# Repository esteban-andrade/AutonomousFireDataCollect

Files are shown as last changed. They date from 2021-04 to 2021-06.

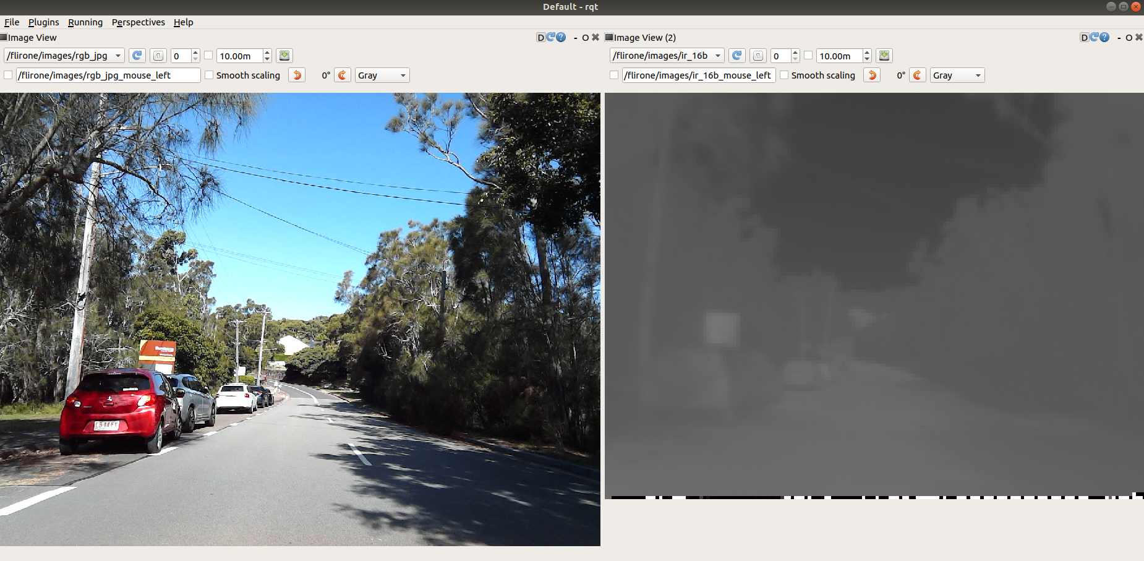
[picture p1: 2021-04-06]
flir_one_node/demo/Screenshot from 2021-02-14 20-05-20.png

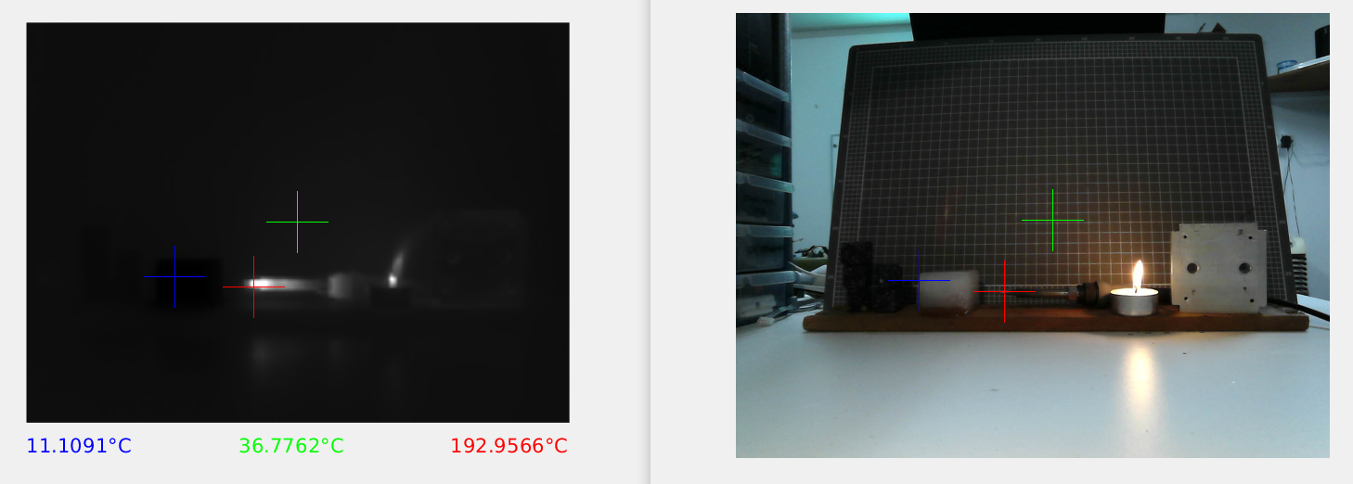
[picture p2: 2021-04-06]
flir_one_node/demo/Screenshot from 2021-02-16 15-40-37.png

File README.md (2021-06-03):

# AutonomousFireDataCollect

This repository deals with the Data Monitoring & Collection for Early-Stage Bushfires project for MMD AUT2021 held at UTS.

In recent years, there has been an international increase in the number, severity, and impact of bushfires on rural communities, biodiversity and subsequently both national and international economies. Currently, emergency services have no method to detect or collect data to monitor the early stages of remote bushfires. 

Currently, emergency services have limited methods to collect data to detect or monitor remote bushfires in their early stages. The first step is to build up a dataset of bushfire information from a range of sensors. A basic user-responsive prototype has been produced to collect and monitor bushfire data in low intensity areas which has been showcased here.



The following folders contain a solution that aids to capture data in order to train som ML models.

The main objective is to capture data using a thermal camera(Flir) along with auxiliary sensors(Temperature,Humidity,Pressure,etc.).
This will be processed using a corresponding ROS NODE ` flir_one_node` and with the Launch files start the data acquisition process smoothly and store it in a ROSBAG with the timestamp.

All Main components of this project are detailed in the folder below

* The Data Processing folder contains the script required to plot data in MATLAB from a video source and data set.
* The Electronics folder contains the code and PCB schematic/design files created for the prototype device.
* The Interaction folder contains the scripts required to accept commands from the Teensy device to the computer to trigger start and stop recording.
* The flir_one_node folder contains the files required to setup the FLIR ONE camera.

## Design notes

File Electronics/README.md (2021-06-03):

# Electronics

#### The code folder contains the firmware required for the following microcontrollers:
1. [`Sensors-Teensy4.0`](https://github.com/esteban-andrade/AutonomousFireDataCollect/tree/main/Electronics/code/Sensors-Teensy4.0): Once loaded onto the Teensy 4.0, it's main purpose is to collect data from all attached sensors and parse the data over Serial to ROS SERIAL. The device will all the user to start and stop data recording using a user interface panel on board.
2. [`ESP8266`](https://github.com/kyleprr/AutonomousFireDataCollect/tree/main/Electronics/Atmega328p-GPS): The ESP8266 module is intended to collect GPS NEMA data and translate that into GPS coordinates for use. The ESP8266 will parse the data and send it over UART to the Teensy 4.0. 

Note: The firmware is written in VSCode using PlatformIOIDE. Please install the required software to modify the code.

The pcb_project_files folder contains the Altium Designer schematic and PCB files for the four PCB modules as shown below:

### Custom Printed Circuit Boards Developed

#### 1. Main Controller:


#### 2. Power Management:


#### 3. Sensors:


#### 4. User Controller:


#### 5. Connections/Layout:


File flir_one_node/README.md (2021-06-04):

# FLIR One Interfacing Node

This package is used to open a connection to the FLIR one camera and publish data from it to various ROS topics.

This guide assumes that [ROS](https://www.ros.org/) has been installed and setup on the user's system

Package has been tested using `ROS Melodic` running on `Ubuntu 18.04`

## 1. Allow access to USB device

The FLIR One has a vendor ID of `0x09CB` and a porduct ID of `0x1996`

To allow the package to access data from this, create a new `rules` file

```
sudo nano /etc/udev/rules.d/51-usb-flir-one.rules
```

Add the following text to this file

```
SUBSYSTEMS=="usb", ATTRS{idVendor}=="09cb", ATTRS{idProduct}=="1996", MODE:="0666"
```

Restart the system

## 2. Create and run the ROS package

Ensure that this git repository is contained within the `src` folder of the `catkin_ws` directory.

Run `catkin_make` from within the `catkin_ws` directory. Otherwise perform a `catkin build`

Ensure the package can be run by executing the following command from the `catkin_ws` directory: 

```
source devel/setup.bash
```

If there is an issue once when running the program starts on the computer unit. Refresh the bashrc.
```
source devel/setup.bash
```

Ensure an instance of ROS is running on the machine

```
roscore
```

Ensuring the camera is connected and powered on, run the ROS package

```
rosrun flir_one_node flir_one_node
```
## Launch Files

Alternatively there are a series of launch files that can be used to start the rosnode. These will allow a simpler approach when executing the ROS nodes for different purposes such as Visualization or Data Recording

### For Visualization 

Type the following command in a terminal. It will start the node and it will broadcast both RBG and Depth Images

```
roslaunch flir_one_node flir_data_vis.launch
```

### For Recording
 
 Type the following command in the terminal to record a ROSBAG of images and sensor data. The ROSBAG will use the timestamp of when the recording process started.
 
```
roslaunch flir_one_node flir_data_vis.launch
```

The data can be viewed using RQT (or similar) on the following topics:

```
/camera_flir_node/rgb/image_raw
/camera_flir_node/ir_8b/image_raw
/camera_flir_node/ir_16b/image_raw
/flirone/ok/status 
/sensors/data
```
The `/flirone/ok/status ` will broadcast the status of the connection of the Flir camera with the Intel Nuc. A boolean will be used and if the value is true there are no issues when using camera to record data.

If the Visualization Launch file is triggered it will use RQT as default for image visualization

## SensorData

The sensor data will be parsed using strings. 
Ensure that the microcontroller is defined as `/dev/ttyACM0`

The Node will send serial data to the microcontroller when it  is required to start and stop the sensor data acquisition process.

he topic `/sensors/data` will receive the sensor data from the teensy and it will parse the serial data as string and subsequenly advertised in this ROS topic.

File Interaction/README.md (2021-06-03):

# Interaction Section

This component describes the integration between the user interface and the system.

## Requirements.
Ensure to navigate to the `test folder` and compile the test  script
```
mkdir build 
cd build 
cmake ..
make
````

## Specifications.
This will generate an executable(program) that will be added to the `start-up` applications in ubuntu in order to start it automatically after boot.

It will read data from the serial port `/dev/ttyACM0` amd it will wait from input from the user in order to start recording data.

Once the user pressed the stop button it will terminate the data recording process.

## Integration
To integrate this open the `start-up` applications option in Ubuntu.
Add the path to the filed to the generated executable  `integration` to the new option and add a valid name.

Once the system reboots the application will start automatically.

## Extra components
Similarly under PythonSerial it is possible to user seral pythons scripts to acquire pure sensor data from the teensy and save them to CSV files.

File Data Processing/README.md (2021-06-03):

# MATLAB Data Plotting Video Generator

This document outlines how to use the MATLAB script `data_plotter.m` to visualise time-based graphical data with a live video.

## Dependencies

This script was prepared using MATLAB R2021a. No specialised toolboxes are required for use.

## Purpose and Overview

The purspose of this program is to take a descrete time-based dataset in a `.csv` format and visualise that data against a video in realtime.

## Usage Instructions

To use this script, a csv and supported video file is required, and should be placed within your MATLAB workspace.

These filenames should be placed in lines 6 and 9:

```
% Load data to plot
sensorData = readtable('<csv_file>');

% Load video to plot
v = VideoReader('<video_file>');
```

Lines 1-3 should be updated to show the rate at which data is captured in the csv file, the frame rate of the video and the frame number within the video where the data starts recording:

```
data_poll_rate_hz = 1;
frame_rate_fps = 30;
start_frame = 222;
```

Lines 11-55 setup the interface, and may be modified should elements of the GUI require changing, such as aspect ratio, video size or number of graphics.

Lines 58-62 create the video object to output. Here, the file format, frame rate and compression ratio (quality) can be set.

If the original video needs to be rotated, this can be done on line 69:

```
frame = imrotate(frame, 270);
```

Lines 80-113 plot the figures, and needs to be configured depending on what data you wish to show, and how you wish to show it.

For example, line 81 can be configured to extract the appropriate data from the csv table, as well as format the plot.

## Disclaimer

It is acknowledged that the modularity of this script is limited, and can be improved in several ways. The user should understand that this script was developed as a "hacky prototype" used to visualise data for a specific application. This software is provided "as is" and is used at your own risk.

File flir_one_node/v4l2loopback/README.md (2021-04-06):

# Using Video for Linux 2 (V4L2)

In the case where ROS is not available, the video data from the FLIR One can be streamed to Linux by running the appropriate drivers. This can be useful for testing and evaluation purposes.

## Testing Conditions

This procedure was tested on the following machines and operating systems:

1. DELL XPS 13 (with UEFI Secure Boot)
```
Kernel: 5.4.0-60-generic x86_64
bits: 64
Desktop: Gnome 3.28.4
Distro: Ubuntu 18.04.5 LTS
```

2. Lattepanda SBC
```
Ubuntu 16.04
```

## Device Setup

Install the following packages using the following

```
$ sudo apt-get install g++
$ sudo apt-get install libusb-1.0-0-dev
$ sudo apt-get install linux-generic
$ sudo apt-get install mplayer
```

Install `v4l2loopback` from [github](https://github.com/umlaeute/v4l2loopback). Follow the instructions in this repository to install.

To check that `v4l2loopback` has installed correctly, run the following:

```
$ sudo modprobe v4l2loopback
```

This will create a new virtual video device for the physical video devices connected to your system.

If an error message is received, refer to the troubleshooting steps in the `v4l2loopback` documentation. This will likely occur on UEFI secure boot devices, in which case, the module should be built [via DKMS](https://github.com/umlaeute/v4l2loopback#DKMS).

When working with DKMS, you need to be superuser through either of the following:

```
$ su
$ sudo -i
```

## Install

The first step is to create new dummy video devices for the FLIR One camera for the three image streams.

Assign a virtual video device to each existing video device and check what devices are connected to the system:

```
$ sudo modprobe v4l2loopback
$ v4l2-ctl --list-devices
```

You should see a list of devices and an associated video. You can also list the virtual video devices used as follows:

```
$ ls /dev/video*
```

Create the three new virtual video devices using the following command:

```
$ sudo modprobe v4l2loopback devices=3
```

Alternatively, you can specify the video number and name with the following

```
$ sudo modprobe v4l2loopback video_nr=<N>,<N+1>,<N+2> card_label="<Device name N>","<Device name N+1>","<Device name N+2>"
```

where N is the next available virtual video device.

For example, the following device has an internal webcam and two external USB cameras. Listing the devices gave the following result:

```
$ v4l2-ctl --list-devices
Integrated_Webcam_HD: Integrate (usb-0000:00:14.0-5):
	/dev/video0
	/dev/video1
	/dev/video2
	/dev/video3

USB2.0 UVC PC Camera: USB2.0 UV (usb-0000:3c:00.0-2.3.2.1.1.1):
	/dev/video4
	/dev/video5

Microsoft® LifeCam Studio(TM): (usb-0000:3f:00.0-1.2):
	/dev/video6
	/dev/video7
```

As there are eight devices already (0-7), three new additional devices will be created as video8, video9 and video10:

```
$ sudo modprobe v4l2loopback devices=3
$ v4l2-ctl --list-devices
Dummy video device (0x0000) (platform:v4l2loopback-000):
	/dev/video8

Dummy video device (0x0001) (platform:v4l2loopback-001):
	/dev/video9

Dummy video device (0x0002) (platform:v4l2loopback-002):
	/dev/video10

Integrated_Webcam_HD: Integrate (usb-0000:00:14.0-5):
	/dev/video0
	/dev/video1
	/dev/video2
	/dev/video3

USB2.0 UVC PC Camera: USB2.0 UV (usb-0000:3c:00.0-2.3.2.1.1.1):
	/dev/video4
	/dev/video5

Microsoft® LifeCam Studio(TM): (usb-0000:3f:00.0-1.2):
	/dev/video6
	/dev/video7
```

If not all dummy videos were created, you can try and reset v4l2loopback, which is loaded on boot (may occur especially if multiple video devices are connected). Recreate the devices again as follows:

```
$ sudo rmmod v4l2loopback
$ sudo modprobe v4l2loopback devices=3
$ v4l2-ctl --list-devices
```

The source code of [flirone.c](src/flirone.c) needs to then be modified to assign the video streams to one of these virtual devices (lines 41-51). Only the string for the video device name needs to be changed

```
#define VIDEO_DEVICE0 "/dev/video8"  // gray scale thermal image
#define FRAME_WIDTH0  160
#define FRAME_HEIGHT0 120

#define VIDEO_DEVICE1 "/dev/video9" // color visible image
#define FRAME_WIDTH1  640
#define FRAME_HEIGHT1 480

#define VIDEO_DEVICE2 "/dev/video10" // colorized thermal image
#define FRAME_WIDTH2  160
#define FRAME_HEIGHT2 128
```

Compile the code by running

```
$ make
```

## Run

Power on the FLIR One device and connect it to your machine. It is recommended to use a connection system that supports USB3.0 or higher

Wait until the FLIR One has completely powered on, and the Green LED is blinking on the power button.

Run the FLIR driver with a palette from the [palletes](palettes) folder. For example:

```
$ ./flirone palettes/7.raw 
```

While the above script is running, open a new terminal window and run:

```
$ mplayer tv:// -tv driver=v4l2:device=/dev/<videoN>
```

where videN is one of the three video devices you created earlier, for example:

```
$ mplayer tv:// -tv driver=v4l2:device=/dev/video8
```

You should now see a stream of the video from the FLIR One.

## References

<https://www.eevblog.com/forum/thermal-imaging/question-about-flir-one-for-android/msg832208/#msg832208>

<https://github.com/umlaeute/v4l2loopback>

<https://github.com/fnoop/flirone-v4l2>

<https://news.ycombinator.com/item?id=22805925>

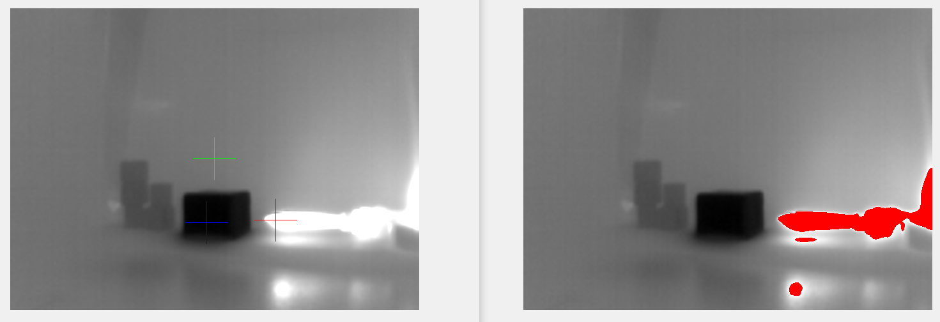
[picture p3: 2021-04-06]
flir_one_node/demo/Screenshot from 2021-02-16 16-03-00.png

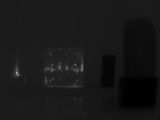
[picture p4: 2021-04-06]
flir_one_node/v4l2loopback/new3.png

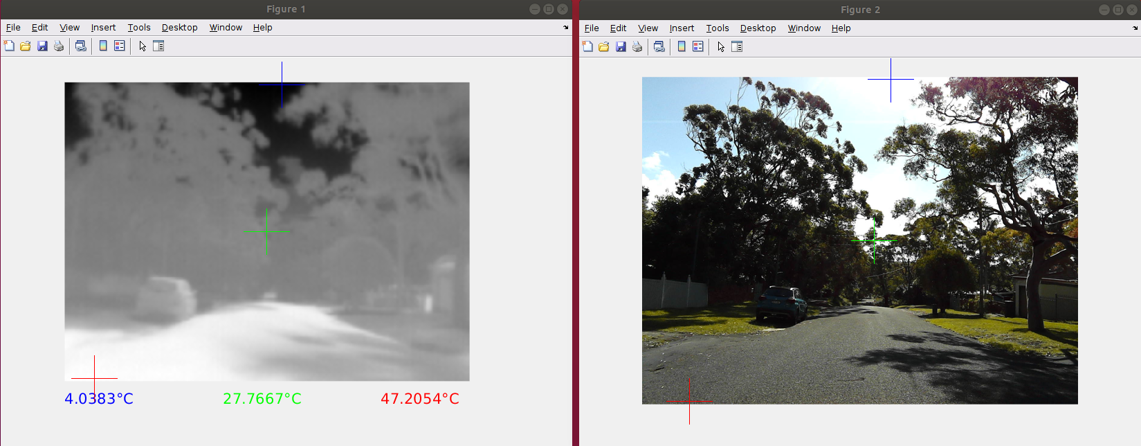
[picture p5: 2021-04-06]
flir_one_node/demo/Screenshot from 2021-02-15 16-33-07.png

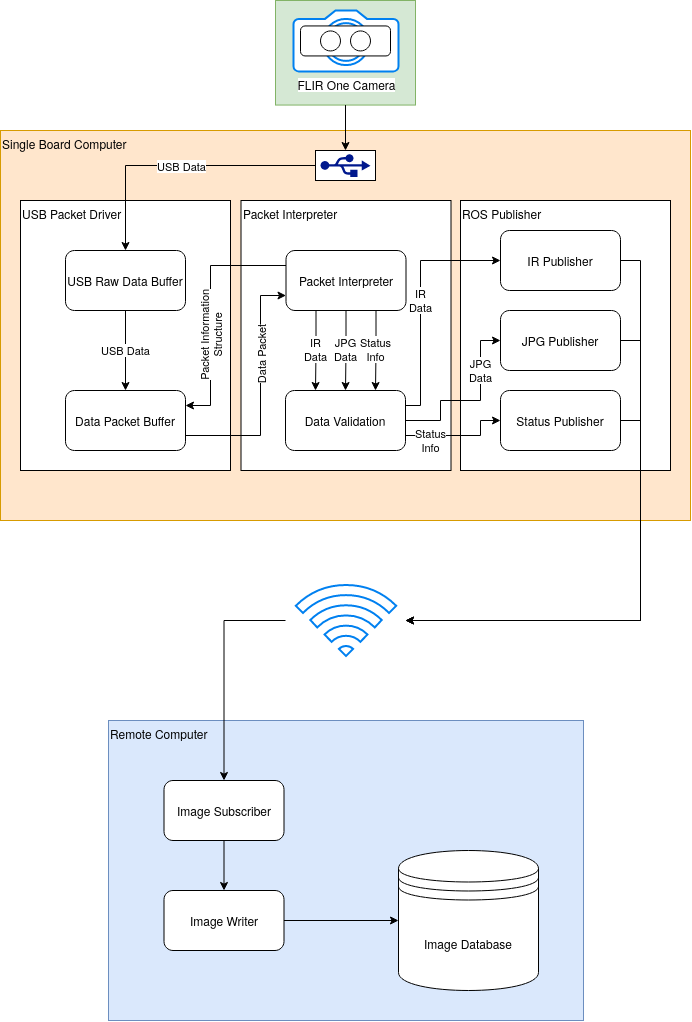
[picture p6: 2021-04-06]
flir_one_node/info/flow_chart/FLIR One ROS Driver.png

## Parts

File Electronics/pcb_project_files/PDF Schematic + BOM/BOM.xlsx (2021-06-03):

Part | Description | Designator | Qty | Digikey |  | Link
100uF | CAP ALUM 100UF 20% 25V SMD | C1 | 1 |  | EEE-1EA101AP | https://www.digikey.com.au/product-detail/en/panasonic-electronic-components/EEE-1EA101AP/PCE4593CT-ND/1718016
0.1uF | CAP CER 0.1UF 50V X7R 0603 | C1, C2, C3, C4,C5, C6, C7, C8,C2, C7, C9, C11,C13, C14 | 14 |  | 1276-CL10B104KB8NNNLCT-ND | https://www.digikey.com.au/products/en?keywords=1276-CL10B104KB8NNNLCT-ND
0.33uF | CAP CER 0.33UF 35V X7R 0603 | C8, C10, C12 | 3 |  | CGA3E1X7R1V334K080AC | https://www.digikey.com.au/product-detail/en/tdk-corporation/CGA3E1X7R1V334K080AC/445-6927-1-ND/2672945
10uF | CAP CER 10UF 16V X5R 0603 | C5 | 1 |  | 587-3238-1-ND | https://www.digikey.com.au/products/en?keywords=587-3238-1-ND
1uF | CAP CER 1UF 25V X5R 0603 | C6 | 1 |  | 1276-1102-1-ND | https://www.digikey.com.au/products/en?keywords=1276-1102-1-ND
0R | RES 0 OHM JUMPER 1/10W 0603 | R17, R18 | 2 |  | RMCF0603ZT0R00TR-ND | https://www.digikey.com.au/products/en?keywords=RMCF0603ZT0R00TR-ND
10k | RES SMD 10K OHM 1% 1/10W 0603 | R1, R2, R3, R4,R2, R7, R8, R9, R10, R11,R16 | 11 |  | A121523CT-ND | https://www.digikey.com.au/products/en?keywords=A121523CT-ND
10k NTC | THERMISTOR NTC 10KOHM 4250K 0603 | R3 | 1 |  | P10547CT-ND | https://www.digikey.com.au/products/en?keywords=P10547CT-ND
4k7 | RES SMD 4.7K OHM 1% 1/10W 0603 | R12, R13, R14, R15 | 4 |  | 311-4.70KHRCT-ND | https://www.digikey.com.au/products/en?keywords=311-4.70KHRCT-ND
ESP8266-12E/ESP-12E | RX TXRX MOD WIFI TRACE ANT SMD | U6 | 1 |  | 1528-1438-ND | https://www.digikey.com.au/products/en?keywords=1528-1438-ND
MQ-2 | MQ-2 Gas Sensor | U7,U9 | 2
BME680 | SENSOR RH PRESSURE TEMP VOC | U8 | 1 |  | 828-1077-1-ND | https://www.digikey.com.au/products/en?keywords=828-1077-1-ND
MC7812BDTRKG | IC REG LINEAR 12V 1A DPAK | U10 | 1 |  | MC7812BDTRKGOSCT-ND | https://www.digikey.com.au/products/en?keywords=MC7812BDTRKGOSCT-ND
MC7805CDTRKG | IC REG LINEAR 5V 1A DPAK | U11 | 1 |  | MC7805CDTRKGOSCT-ND | https://www.digikey.com.au/products/en?keywords=MC7805CDTRKGOSCT-ND
BA033CC0FP-E2 | IC REG LINEAR 3.3V 1A TO252-3 | U12 | 1 |  | BA033CC0FP-E2CT-ND | https://www.digikey.com.au/products/en?keywords=BA033CC0FP-E2CT-ND
SWITCH TACTILE SPSTNO 0.05A 24V | SWITCH TACTILE SPSTNO 0.05A 24V | SW1,SW2,SW3,SW4 | 4 |  | 450-1650-ND | https://www.digikey.com.au/products/en?keywords=450-1650-ND
WS2812B | WS2812B | U1,U2,U3,U4 | 4
Screw Terminal |  |  | 1
XT60-M |  |  | 1

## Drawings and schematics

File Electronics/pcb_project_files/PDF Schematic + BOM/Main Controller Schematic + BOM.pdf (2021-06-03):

### Teensy 4.0 - MCU1

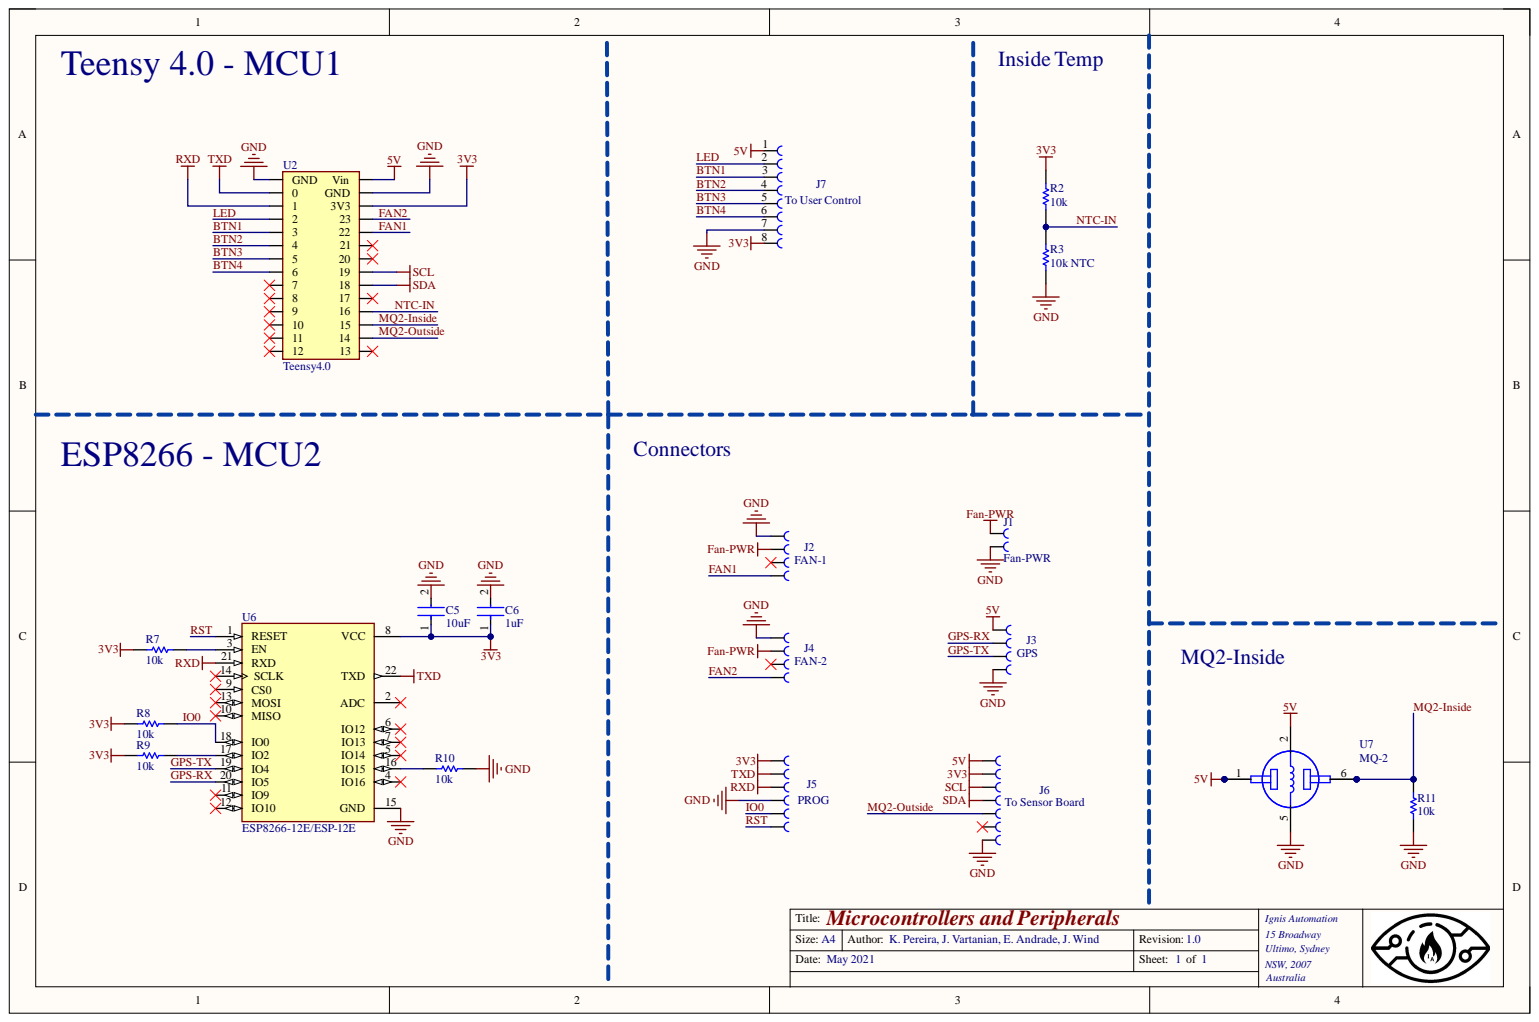
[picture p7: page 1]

GPS-RX GPS-TXGN

GPS-RX GPS-TX

Size : A 4 | A u t h o r : K. Pereira, J. Vartan ian, E. A n drade, J. W i n d | Rev i s i o n : 1 . 0
Dat e : May 2 0 2 1 | | Sheet : 1 o f 1

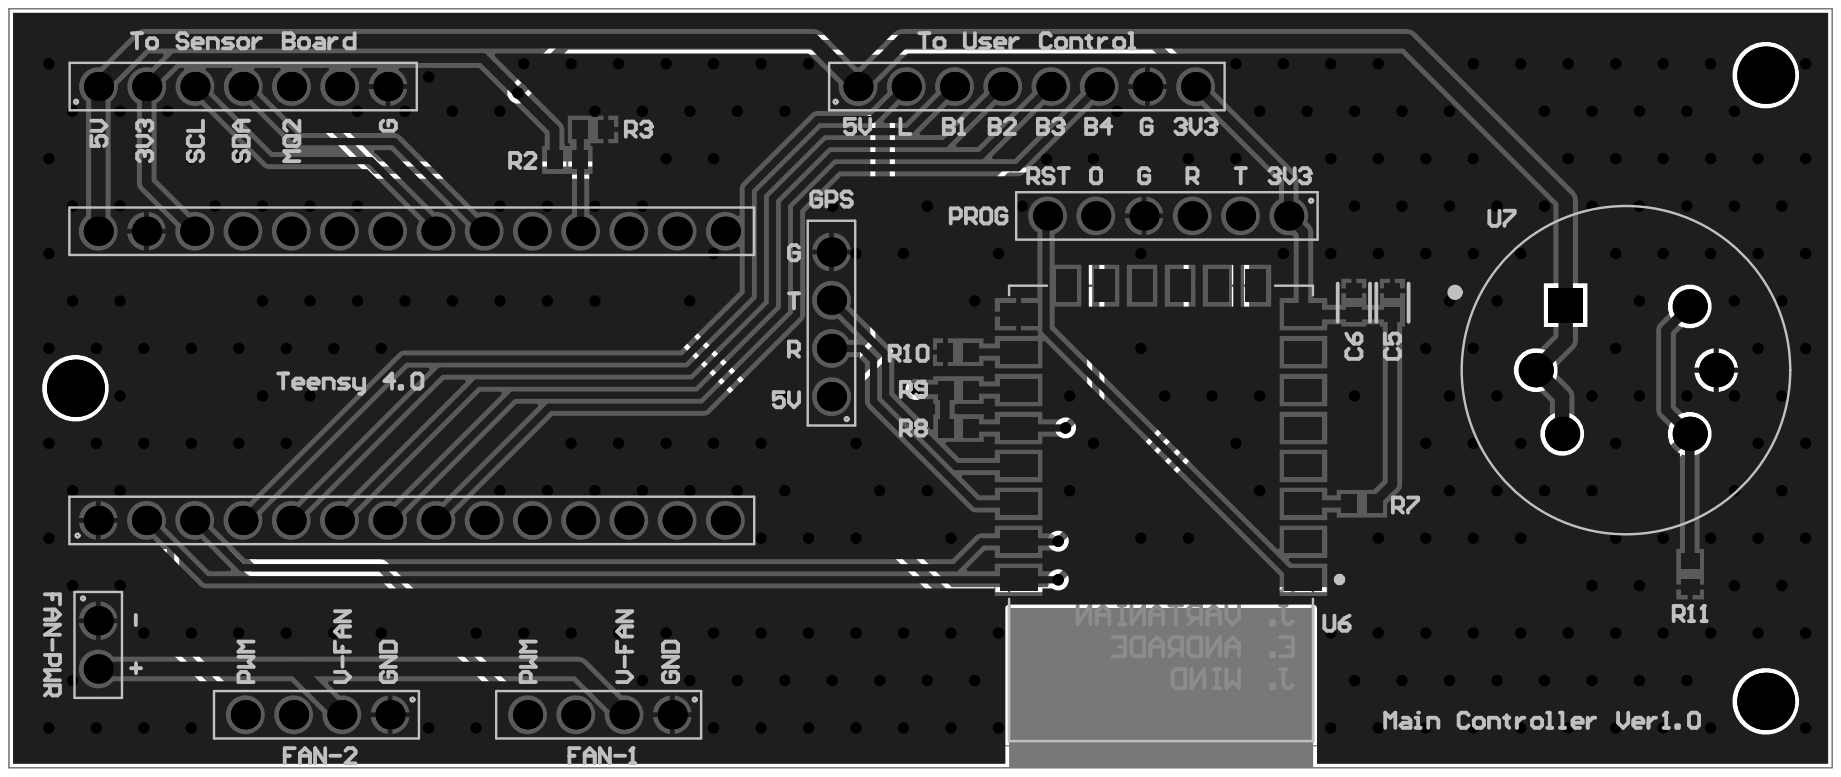
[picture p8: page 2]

Comment | Description | Designator | Footprint | LibRef | Quantity
10uF | CAP CER 10UF 16V X5R 0603 | C5 | FP-CL10-IPC_C | CMP-13271-003248-1 | 1
1uF | CAP CER 1UF 25V X5R 0603 | C6 | FP-CL10-IPC_C | CMP-13271-003248-1 | 1
Fan-PWR | 2 Pin | J1 | 61300711821 | 61300711821 | 1
FAN-1 | 4 Pin | J2 | 61300711821 | 61300711821 | 1
GPS | 4 Pin | J3 | 61300711821 | 61300711821 | 1
FAN-2 | 4 Pin | J4 | 61300711821 | 61300711821 | 1
PROG | 6 Pin | J5 | 61300711821 | 61300711821 | 1
To Sensor Board | 7 Pin | J6 | 61300711821 | 61300711821 | 1
To User Control | 8 Pin | J7 | 61300711821 | 61300711821 | 1
10k | RES SMD 10K OHM 1% 1/10W 0603 | R2, R7, R8, R9, R10, R11 | RESC1608X55X30NL15 T15 | CMP-2000-00180-1 | 6
10k NTC | THERMISTOR NTC 10KOHM 4250K 0603 | R3 | RESC1608X55X30NL15 T15 | CMP-2000-00180-1 | 1
Teensy4.0 | Teensy4.0 | U2 | 61301411821 | Teensy4.0 | 1
ESP8266-12E/ESP-12E | RX TXRX MOD WIFI TRACE ANT SMD | U6 | XCVR_ESP8266-12E/ESP-12E | ESP8266-12E/ESP-12E | 1
MQ-2 | MQ-2 Gas Sensor | U7 | XDCR_SEN-08880 | MQ-2 | 1

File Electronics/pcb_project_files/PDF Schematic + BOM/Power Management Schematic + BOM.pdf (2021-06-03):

LiPo Battery | Intel NUC

### Voltage Regulators

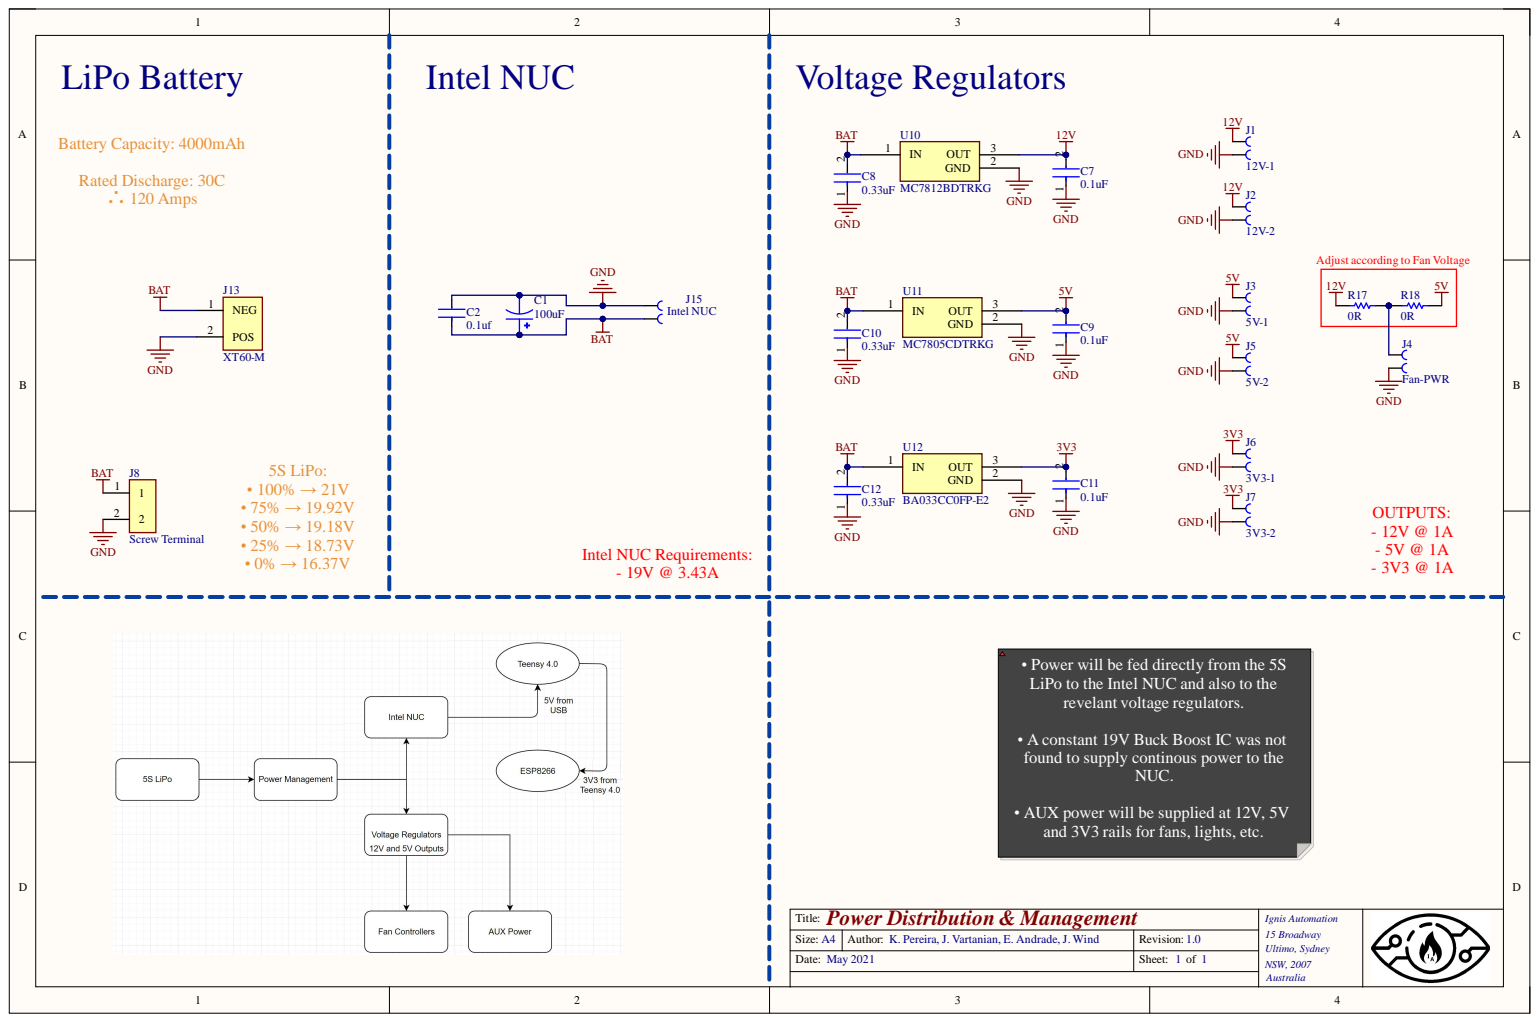
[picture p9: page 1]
tel; 5S LiPo: • 100%; Intel; UC Requirements: - 19V @ 3.43A; Bat; tery Capaci; Rated; ischarge: 30C ∴ 120; mps; BAT; t accord; o Fan; tag; UTPUTS: - 12V @ 1A - 5V @ 1A - 3V3 @ 1A; BAT GND; Fan-PW; Screw; Termi; nal; Igni; s Automat; ion; roadway; mo, Sydne; NSW, 2007 Australia; Power Distribution & Management itle:; • Power; the 5S; LiPo; the; revelant vol; tage regulators.; was not; found; inous power; X power; l be suppl; ied at 12V; and 3V3 rai; ights, etc.

l be fed direct

ly from
UC and also

A constant 19V Buck Boost
to supply cont

ls for fans,

Size : A 4 | A u t h o r : K. Pereira, J. Vartan ian, E. A n drade, J. W i n d | Rev i s i o n : 1 . 0
Dat e : May 2 0 2 1 | | Sheet : 1 o f 1

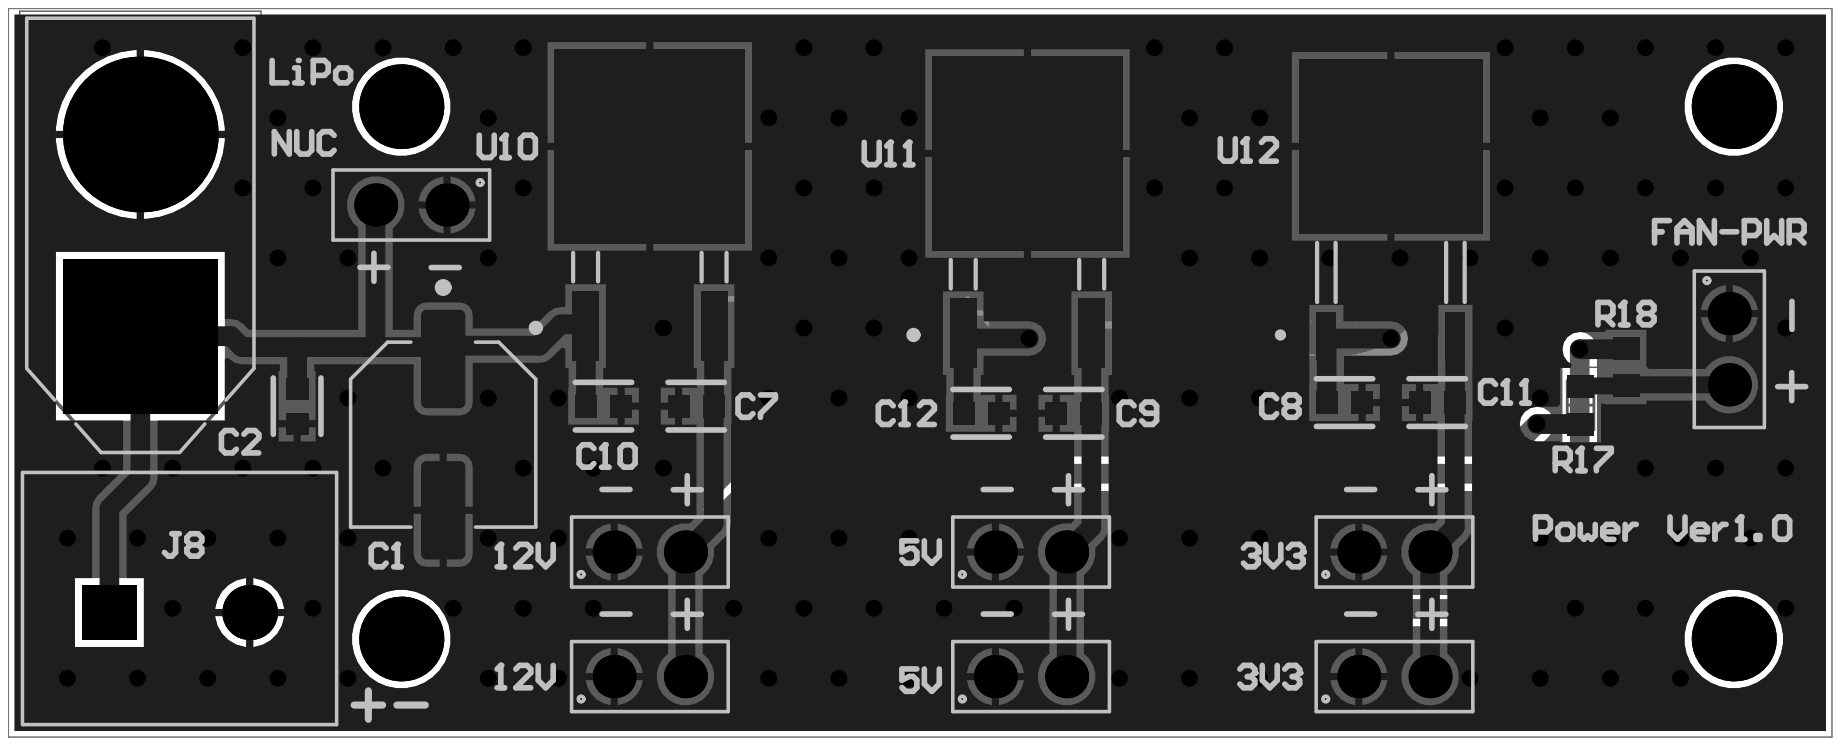
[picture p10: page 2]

Comment | Description | Designator | Footprint | LibRef | Quantity
100uF | CAP ALUM 100UF 20% 25V SMD | C1 | CAPAE660X800N_EEE-FPV101XAP | EEE-FPV101XAP | 1
0.1uf | CAP CER 0.1UF 50V X7R 0603 | C2, C7, C9, C11 | FP-CL10-IPC_C | CMP-13271-003248-1 | 4
0.33uF | CAP CER 0.33UF 35V X7R 0603 | C8, C10, C12 | FP-CL10-IPC_C | CMP-13271-003248-1 | 3
12V-1 | 2 Pin | J1 | 61300711821 | 61300711821 | 1
12V-2 | 2 Pin | J2 | 61300711821 | 61300711821 | 1
5V-1 | 2 Pin | J3 | 61300711821 | 61300711821 | 1
Fan-PWR | 2 Pin | J4 | 61300711821 | 61300711821 | 1
5V-2 | 2 Pin | J5 | 61300711821 | 61300711821 | 1
3V3-1 | 2 Pin | J6 | 61300711821 | 61300711821 | 1
3V3-2 | 2 Pin | J7 | 61300711821 | 61300711821 | 1
Screw Terminal | 2 Position Wire to Board Terminal Block Horizontal with Board 0.197 _5.00mm_ Through Hole | J8 | OST_OSTTA020161 | OSTTA020161 | 1
XT60-M | XT60 | J13 | AMASS_XT60-M | XT60-M | 1
Intel NUC | 2 Pin | J15 | 61300711821 | 61300711821 | 1
0R | RES 0 OHM JUMPER 1/10W 0603 | R17, R18 | RESC1608X55X30NL15 T15 | CMP-2000-00180-1 | 2
MC7812BDTRKG | IC REG LINEAR 12V 1A DPAK | U10 | DPAK-3_ONS | MC7812BDTRKG | 1
MC7805CDTRKG | IC REG LINEAR 5V 1A DPAK | U11 | DPAK-3_ONS | MC7805CDTRKG | 1
BA033CC0FP-E2 | IC REG LINEAR 3.3V 1A TO252-3 | U12 | TO252-3_ROM | BA033CC0FP-E2 | 1

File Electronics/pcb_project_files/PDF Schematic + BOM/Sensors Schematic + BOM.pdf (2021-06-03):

### BME680

### Optical Dust Sensor

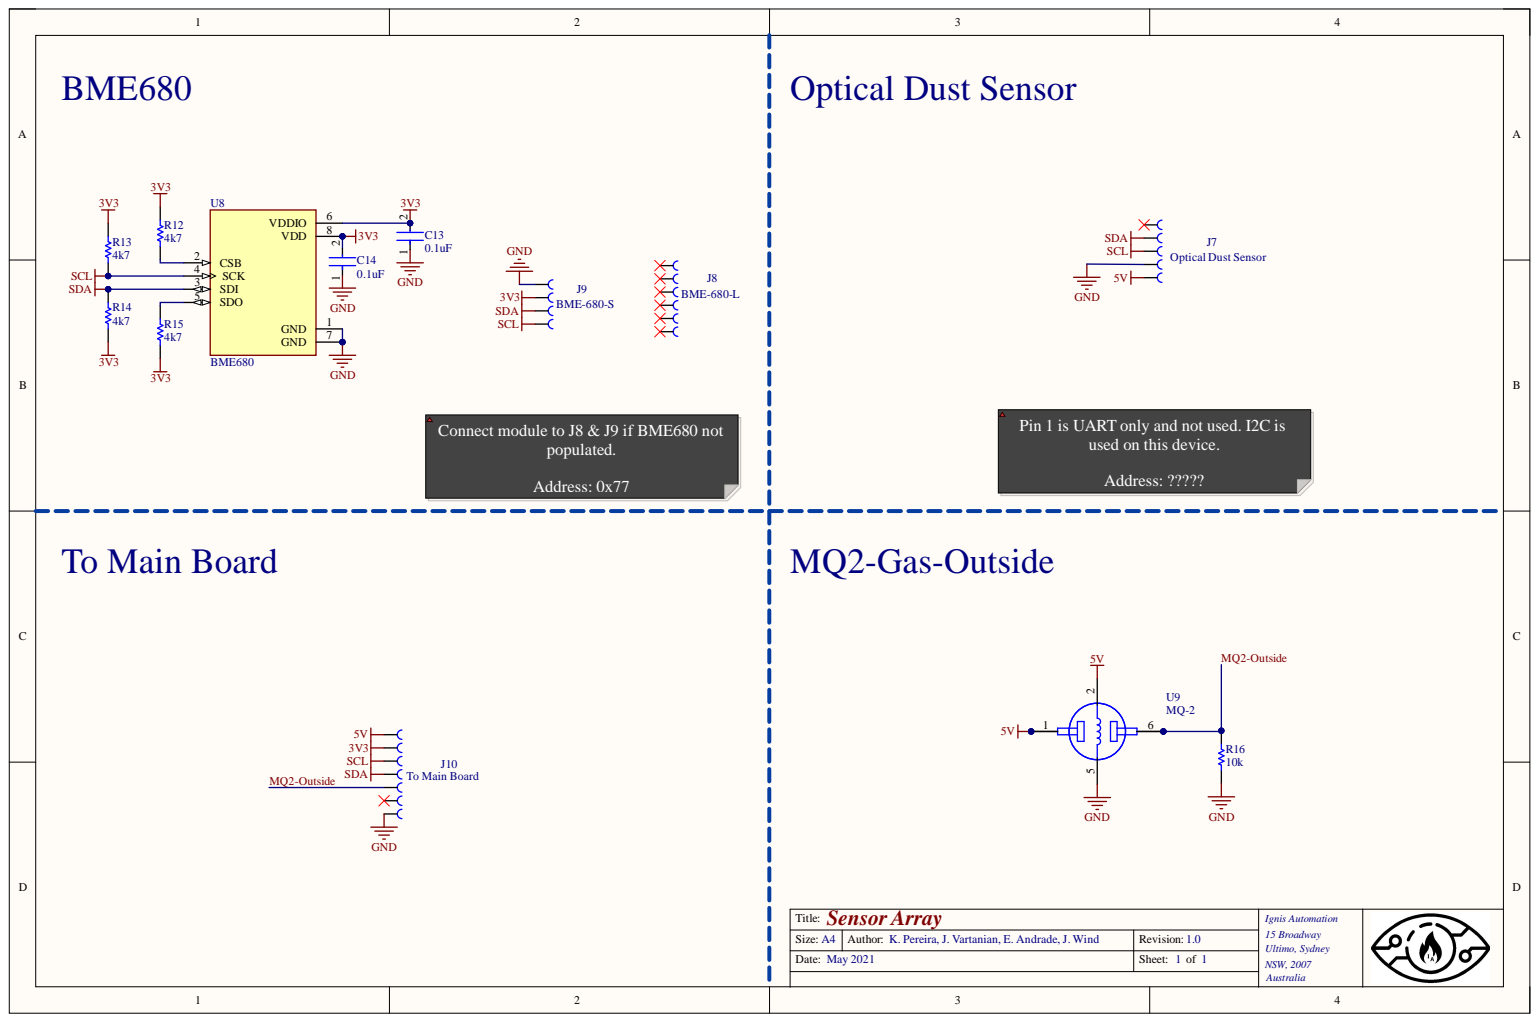
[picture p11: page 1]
Igni; s Automat; ion; roadway; mo, Sydne; NSW, 2007 Australia; : Sensor Array; CSB; SCK; BME; To Mai; n Board; 3 SCL SD; ical; t Sen; A SCL; SCL SD; 8 BME-6; 9 BME-6; To Main Board; MQ2-Gas-Outside ¹ ²; Connect; module; if BME680 not; populat; Address: 0x77; Pin 1; used on; this device.; Address: ?????

RT only and not used.

Size : A 4 | A u t h o r : K. Pereira, J. Vartan ian, E. A n drade, J. W i n d | Rev i s i o n : 1 . 0
Dat e : May 2 0 2 1 | | Sheet : 1 o f 1

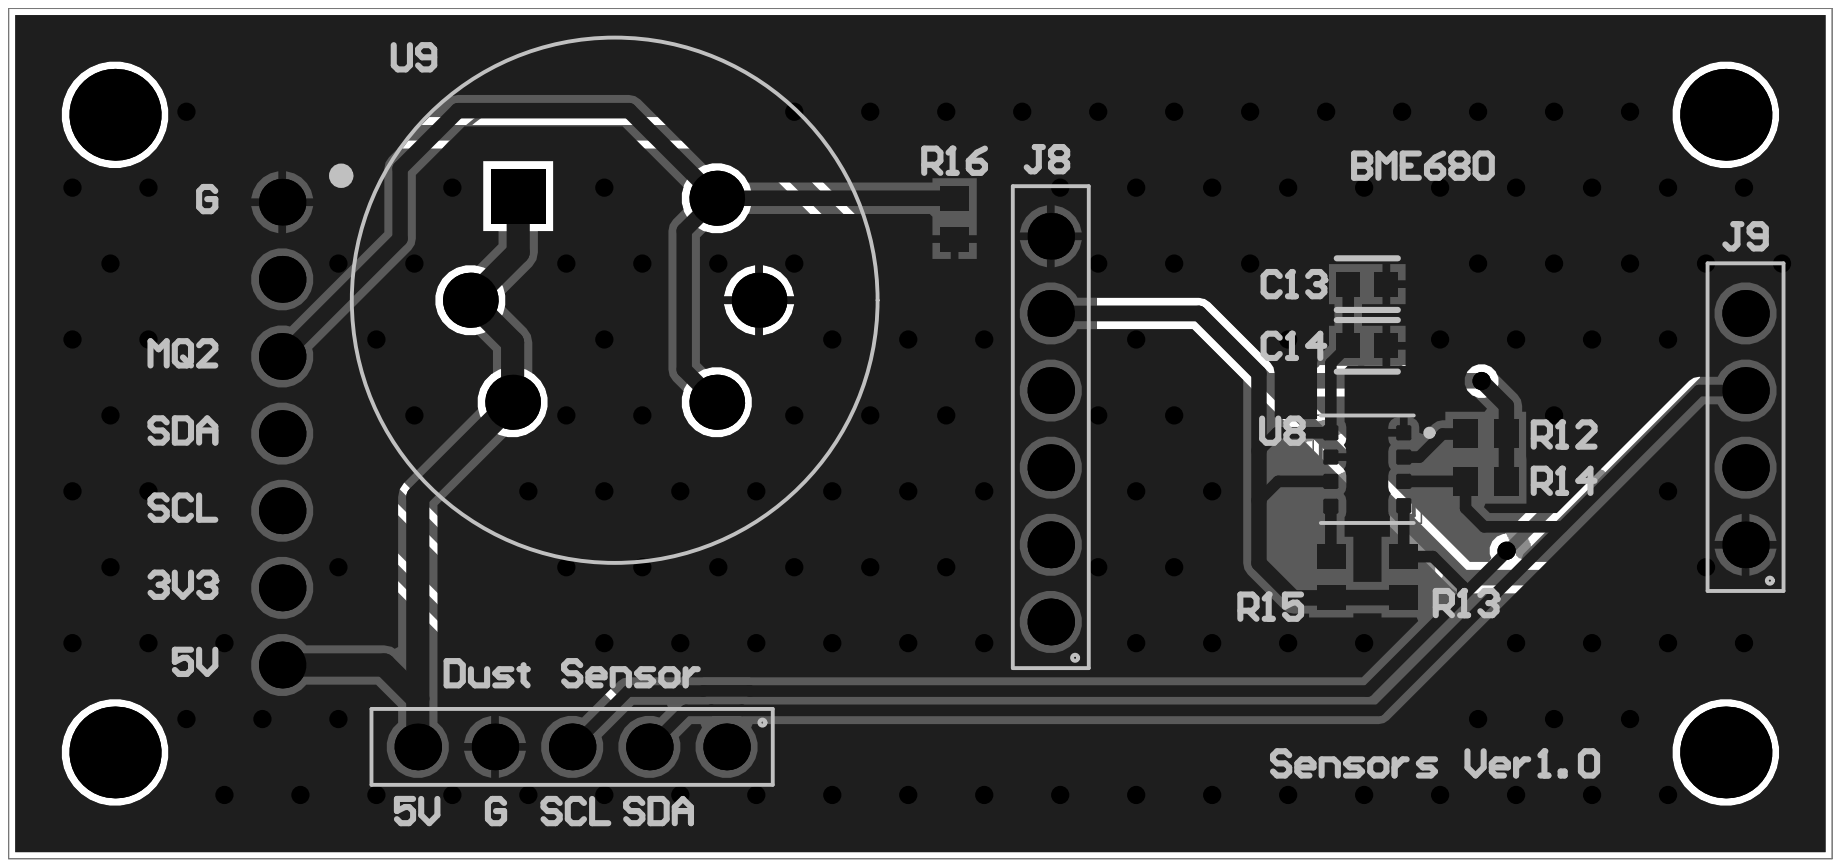
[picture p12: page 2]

Comment | Description | Designator | Footprint | LibRef | Quantity
0.1uF | CAP CER 0.1UF 50V X7R 0603 | C13, C14 | FP-CL10-IPC_C | CMP-13271-003248-1 | 2
Optical Dust Sensor | 5 Pin | J7 | 61300711821 | 61300711821 | 1
BME-680-L | 6 Pin | J8 | 61300711821 | 61300711821 | 1
BME-680-S | 4 Pin | J9 | 61300711821 | 61300711821 | 1
To Main Board | 7 Pin | J10 | 61300711821 | 61300711821 | 1
4k7 | RES SMD 4.7K OHM 1% 1/10W 0603 | R12, R13, R14, R15 | RESC1608X55X30NL15 T15 | CMP-2000-00180-1 | 4
10k | RES SMD 10K OHM 1% 1/10W 0603 | R16 | RESC1608X55X30NL15 T15 | CMP-2000-00180-1 | 1
BME680 | SENSOR RH PRESSURE TEMP VOC | U8 | PSON80P300X300X10 0-8N | BME680 | 1
MQ-2 | MQ-2 Gas Sensor | U9 | XDCR_SEN-08880 | MQ-2 | 1

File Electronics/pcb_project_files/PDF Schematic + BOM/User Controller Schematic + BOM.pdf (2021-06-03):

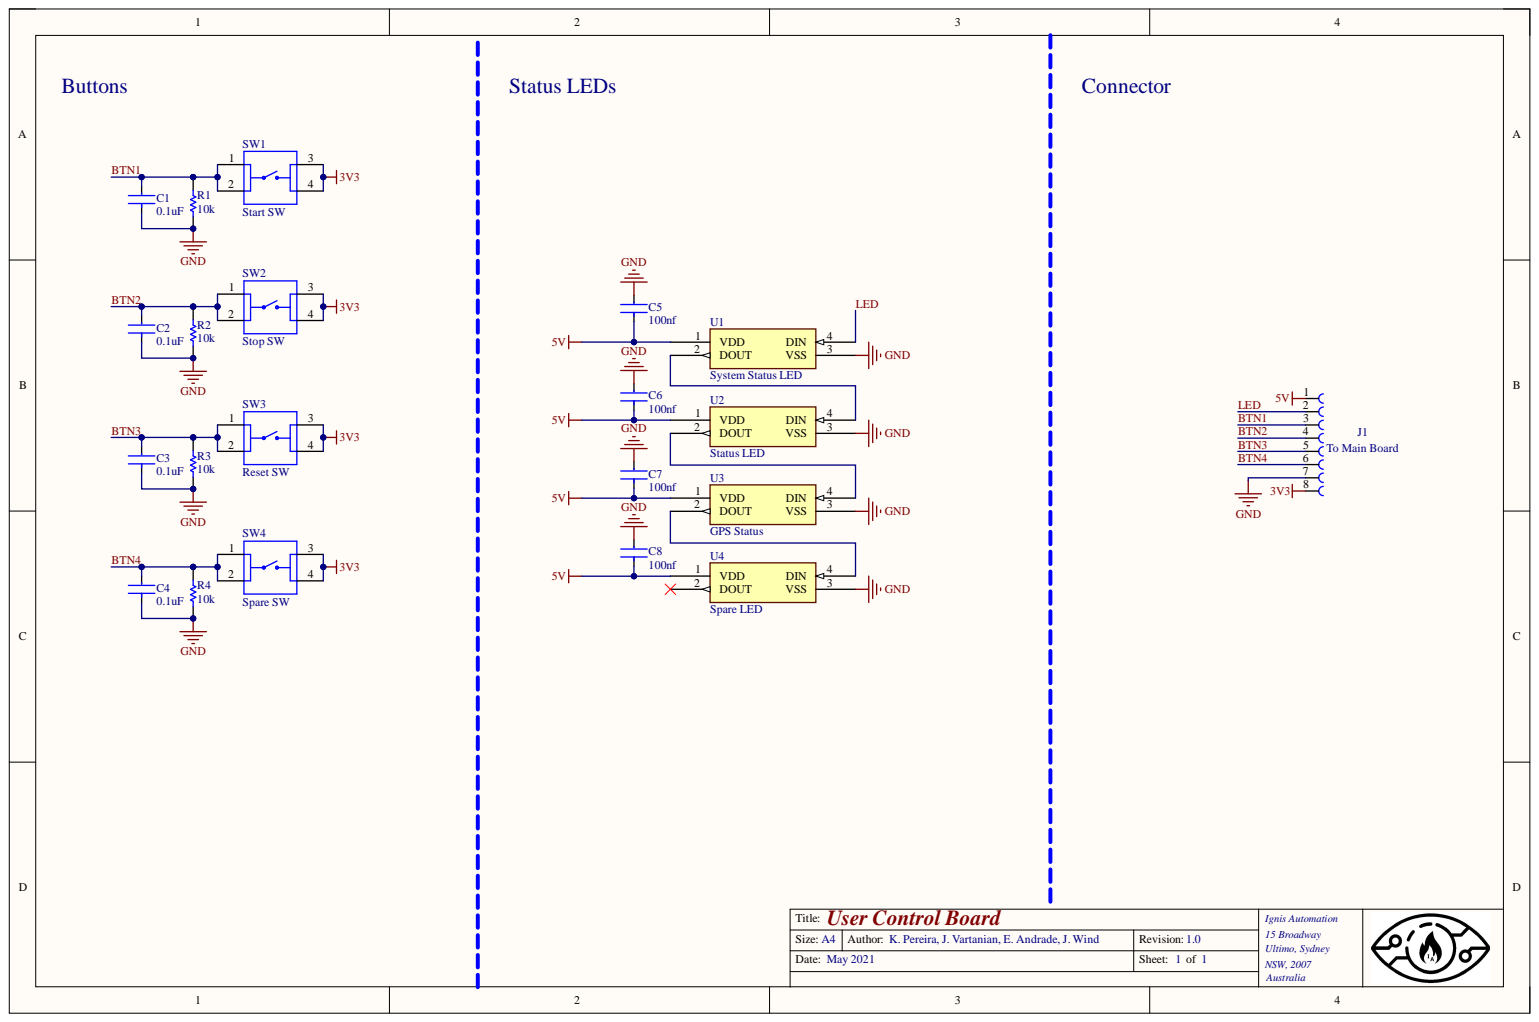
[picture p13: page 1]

Size : A 4 | A u t h o r : K. Pereira, J. Vartan ian, E. A n drade, J. W i n d | Rev i s i o n : 1 . 0
Dat e : May 2 0 2 1 | | Sheet : 1 o f 1

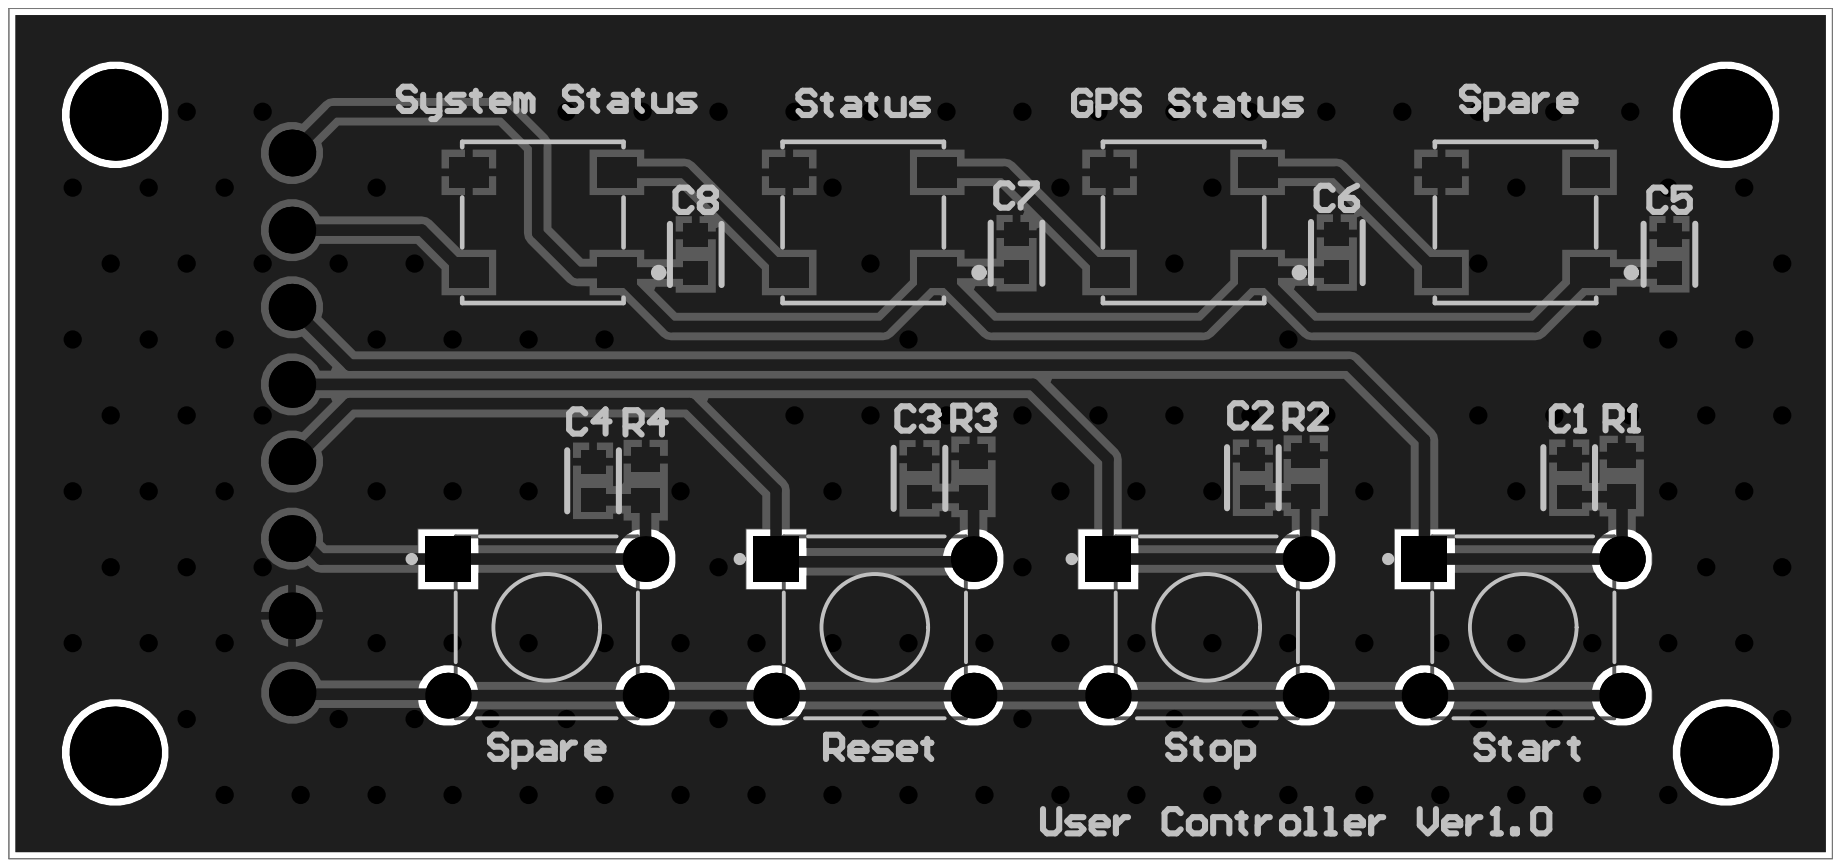
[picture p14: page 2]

Comment | Description | Designator | Footprint | LibRef | Quantity
0.1uF | CAP CER 0.1UF 50V X7R 0603 | C1, C2, C3, C4 | FP-CL10-IPC_C | CMP-13271-003248-1 | 4
100nf | CAP CER 0.1UF 50V X7R 0603 | C5, C6, C7, C8 | FP-CL10-IPC_C | CMP-13271-003248-1 | 4
To Main Board | 8 Pin | J1 | 61300711821 | 61300711821 | 1
10k | RES SMD 10K OHM 1% 1/10W 0603 | R1, R2, R3, R4 | RESC1608X55X30NL15 T15 | CMP-2000-00180-1 | 4
Start SW | SWITCH TACTILE SPST-NO 0.05A 24V | SW1 | SW_1825910-6-4 | 1825910-6 | 1
Stop SW | SWITCH TACTILE SPST-NO 0.05A 24V | SW2 | SW_1825910-6-4 | 1825910-6 | 1
Reset SW | SWITCH TACTILE SPST-NO 0.05A 24V | SW3 | SW_1825910-6-4 | 1825910-6 | 1
Spare SW | SWITCH TACTILE SPST-NO 0.05A 24V | SW4 | SW_1825910-6-4 | 1825910-6 | 1
System Status LED | WS2812B | U1 | WS2812B_WDS | WS2812B | 1
Status LED | WS2812B | U2 | WS2812B_WDS | WS2812B | 1
GPS Status | WS2812B | U3 | WS2812B_WDS | WS2812B | 1
Spare LED | WS2812B | U4 | WS2812B_WDS | WS2812B | 1

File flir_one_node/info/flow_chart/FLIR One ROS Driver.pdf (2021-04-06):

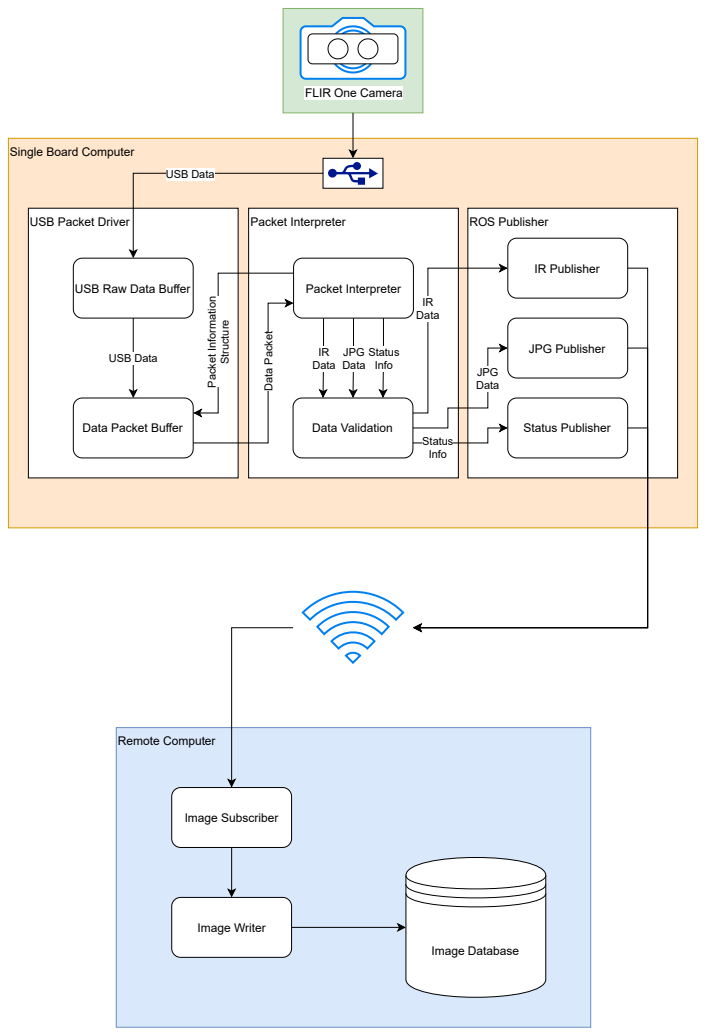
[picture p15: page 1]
Remote Computer; USB Data; Packet Interpreter; Data Validation; Packet Information; Structure; IR Data; JPG Data; Status Info; Data Packet; ROS Publisher; IR Publisher; JPG Publisher; Status Publisher; Image Subscriber; Image Writer; Image Database

FLIR One Camera

Single Board Computer

USB Packet Driver

USB Raw Data Buffer

Data Packet Buffer

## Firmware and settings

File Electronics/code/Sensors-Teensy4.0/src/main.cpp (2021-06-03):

#include <Arduino.h>

#include <Wire.h>
#include <SPI.h>
#include <Adafruit_Sensor.h>
#include <Adafruit_BME680.h>

#include "SparkFun_Particle_Sensor_SN-GCJA5_Arduino_Library.h" //Click here to get the library: http://librarymanager/All#SparkFun_Particle_SN-GCJA5
SFE_PARTICLE_SENSOR myAirSensor;

#define SEALEVELPRESSURE_HPA (1013.25)

Adafruit_BME680 bme; // I2C

unsigned long previousMillis = 0;
const long delayInterval = 1000;
bool sendData = false;

String datapayload;

#include <FastLED.h>
#define LED_PIN 2
#define NUM_LEDS 4
CRGB leds[NUM_LEDS];

int startBtn = 3; //Start button
int stopBtn = 4;  //Stop button
int Start = LOW;
int Stop = LOW;

long lastDebounceTime = 0; // the last time the output pin was toggled
long debounceDelay = 100;  // the debounce time; increase if the output flickers

void setup()
{
  // Initialise Serial
  Serial.begin(115200);

  Wire.begin();

  if (!bme.begin())
  {
    Serial.println(F("Could not find a valid BME680 sensor, check wiring!"));
    while (1)
      ;
  }

  if (myAirSensor.begin() == false)
  {
    Serial.println("The particle sensor did not respond. Please check wiring. Freezing...");
    while (1)
      ;
  }

  // Set up oversampling and filter initialization
  bme.setTemperatureOversampling(BME680_OS_8X);
  bme.setHumidityOversampling(BME680_OS_2X);
  bme.setPressureOversampling(BME680_OS_4X);
  bme.setIIRFilterSize(BME680_FILTER_SIZE_3);
  bme.setGasHeater(320, 150); // 320*C for 150 ms

  pinMode(LED_BUILTIN, OUTPUT);
  digitalWrite(LED_BUILTIN, LOW);

  FastLED.addLeds<WS2812, LED_PIN, GRB>(leds, NUM_LEDS);
  pinMode(startBtn, INPUT);
  pinMode(stopBtn, INPUT);

  for (int i = 0; i < 4; i++)
  {
    leds[i] = CRGB(0, 255, 255); // RED
    FastLED.show();
    delay(100);
  }

  for (int i = 0; i < 4; i++)
  {
    leds[i] = CRGB(175, 220, 255); // Orange
    FastLED.show();
    delay(100);
  }

  for (int i = 0; i < 4; i++)
  {
    leds[i] = CRGB(255, 0, 255); // Green
    FastLED.show();
    delay(100);
  }

  for (int i = 0; i < 4; i++)
  {
    leds[i] = CRGB(255, 255, 255); // OFF
    FastLED.show();
    delay(50);
  }

  leds[0] = CRGB(0, 255, 255); // System Status
  leds[1] = CRGB(108, 0, 255); // Status
  leds[2] = CRGB(255, 255, 0); // GPS Status
  leds[3] = CRGB(0, 255, 255); // Spare
  FastLED.show();
  delay(1000);
  leds[0] = CRGB(255, 0, 255); // System Status

  leds[1] = CRGB(255, 0, 255); // Status
  FastLED.show();
}

void loop()
{

  Start = digitalRead(startBtn);
  Stop = digitalRead(stopBtn);

  //filter out any noise by setting a time buffer
  if ((millis() - lastDebounceTime) > debounceDelay)
  {

    // Start pressed
    if (Start == HIGH && Stop == LOW)
    {
      leds[1] = CRGB(175, 220, 255); // Red
      FastLED.show();
      Serial.write(true);
      lastDebounceTime = millis(); //set the current time

      if (Serial.available())
      {
        char incomingChar = Serial.read();
        // Check for call and response
        if (incomingChar == 'J')
        {
          Serial.print('I');
        }
        if (incomingChar == '0')
        {
          sendData = false;
          digitalWrite(LED_BUILTIN, LOW);
        }
        if (incomingChar == '1')
        {
          sendData = true;
          Serial.println("MQ2-Gas,Temp,Pressure,Humidity,BME680-Gas,PM1.0,PM2.5,PM10,PC0.5,PC1.0,PC2.5,PC5,PC7.5,PC10");
          digitalWrite(LED_BUILTIN, HIGH);
        }
      }
      unsigned long currentMillis = millis();
      if (currentMillis - previousMillis >= delayInterval)
      {
        previousMillis = currentMillis;
        if (sendData)
        {
          int sensorValue = analogRead(A0);
          //Serial.print("MQ2-Gas: ");
          // Serial.print(sensorValue);

          ///////////////////////////////////////////////////////////////////////

          // Tell BME680 to begin measurement.
          unsigned long endTime = bme.beginReading();
          if (endTime == 0)
          {
            Serial.println(F("Failed to begin reading :("));
            return;
          }

          if (!bme.endReading())
          {
            Serial.println(F("Failed to complete reading :("));
            return;
          }
          // Serial.print(",");
          //Serial.print(F("Temperature = "));
          // Serial.print(bme.temperature);
          //Serial.println(F("°C"));

          // Serial.print(",");
          //Serial.print(F("Pressure = "));
          // Serial.print(bme.pressure / 100.0);
          //Serial.println(F("hPa"));

          // Serial.print(",");
          //Serial.print(F("Humidity = "));
          // Serial.print(bme.humidity);
          //Serial.println(F("%"));

          //Serial.print(F("Approx. Altitude = "));
          //Serial.print(bme.readAltitude(SEALEVELPRESSURE_HPA));
          //Serial.println(F("m"));

          // Serial.print(",");
          //Serial.print(F("Gas = "));
          // Serial.print(bme.gas_resistance / 1000.0);
          //Serial.println(F("KΩ"));

          //////////////////////////////////////////////////////////////////////////////

          // Serial.print(",");
          //Serial.print("PM1.0: ");
          float pm1_0 = myAirSensor.getPM1_0();
          // Serial.print(pm1_0, 3); //Print float with 2 decimals

          // Serial.print(",");
          //Serial.print("PM2.5: ");
          float pm2_5 = myAirSensor.getPM2_5();
          // Serial.print(pm2_5, 3);

          // Serial.print(",");
          //Serial.print("PM10: ");
          float pm10 = myAirSensor.getPM10();
          // Serial.print(pm10, 3);

          // Serial.print(",");
          //Serial.print("PC0.5: ");
          unsigned int pc0_5 = myAirSensor.getPC0_5();
          // Serial.print(pc0_5);

          // Serial.print(",");
          //Serial.print("PC1.0: ");
          unsigned int pc1_0 = myAirSensor.getPC1_0();
          // Serial.print(pc1_0);

          // Serial.print(",");
          //Serial.print("PC2.5: ");
          unsigned int pc2_5 = myAirSensor.getPC2_5();
          // Serial.print(pc2_5);

          // Serial.print(",");
          //Serial.print("PC5.0: ");
          unsigned int pc5_0 = myAirSensor.getPC5_0();
          // Serial.print(pc5_0);

          // Serial.print(",");
          //Serial.print("PC7.5: ");
          unsigned int pc7_5 = myAirSensor.getPC7_5();
          // Serial.print(pc7_5);

          // Serial.print(",");
          //Serial.print("PC10: ");
          unsigned int pc10 = myAirSensor.getPC10();
          // Serial.print(pc10);
          String sensor_value = sensorValue;
          String bme_temp = bme.temperature;
          String bme_press = (bme.pressure / 100.0);
          String bme_gass = (bme.gas_resistance / 1000.0);
          String bme_hum = bme.humidity;
          String pm1 = pm1_0;
          String pm2 = pm2_5;
          String pm10_ = pm10;
          String pc0_5_ = pc0_5;
          String pc1_0_ = pc1_0;
          String pc2_5_ = pc2_5;
          String pc5_0_ = pc5_0;
          String pc7_5_ = pc7_5;
          String pc10_ = pc10;

          // datapayload = (sensorValue, bme.temperature, (bme.pressure / 100.0), bme.humidity, (bme.gas_resistance / 1000.0),
          //                (pm1_0, 3), (pm2_5, 3), (pm10, 3), pc0_5, pc1_0, pc2_5, pc5_0, pc7_5, pc10);
          datapayload = sensor_value + ";" + bme_temp + ";" + bme_press + ";" + bme_hum + ";" + bme_gass + ";" + pm1 + ";" + pm2 + ";" + pm10_ + ";" + pc0_5_ + ";" + pc1_0_ + ";" + pc2_5_ + ";" + pc5_0_ + ";" + pc7_5_ + ";" + pc10_;
          Serial.println(datapayload);
        }
      }
    }

    // Stop pressed
    if (Start == LOW && Stop == HIGH)
    {
      leds[1] = CRGB(0, 255, 255); // Green
      FastLED.show();
      delay(1000);
      leds[1] = CRGB(255, 0, 255); // Green
      FastLED.show();
      Serial.write(false);
      lastDebounceTime = millis(); //set the current time
    }
  }
}

// END OF CODE

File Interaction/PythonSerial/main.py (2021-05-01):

import time
import datetime
import sys
import readkey

from serial_list import serial_ports
from serial_handler import SerialHandler, SerialException

READ_DELAY_SECONDS = 0.5
BAUD_RATE = 115200

def getSerialPort():
    serial_port_list = serial_ports()
    valid_serial_port = None
    for serial_port in serial_port_list:
        # Connect to serial port
        serial_device = SerialHandler()
        serial_device.start(serial_port, BAUD_RATE, timeout_seconds = 1)

        # Stop recording if MCU is recording
        serial_device.send_string('0')
        time.sleep(READ_DELAY_SECONDS)

        # Send call to verify connection
        serial_device.send_string('J')
        time.sleep(READ_DELAY_SECONDS)
        response = serial_device.pop_bytes_all()

        # Check if response is valid
        if response == b'I':
            valid_serial_port = serial_port

        # Close connection
        del serial_device

        # If a valid port was found, break
        if valid_serial_port:
            break
        
    return valid_serial_port

def main():
    blocking_readkey = True
    if sys.platform in ('win32', 'cygwin'):
        blocking_readkey = False
    print("Press R to start recording or Q to quit...")
    while True:
        is_recording = False
        # Wait for R to be pressed
        key = readkey.readkey(blocking = blocking_readkey)
        if key == 'r':
            print("Initialising Recording...")
            is_recording = True
        if key == 'q':
            break
        if is_recording:
            valid = False
            device = None
            try:
                port = getSerialPort()
            except Exception as e:
                print("FATAL ERROR {0}".format(e))
                sys.exit(-1)
            valid = True
            timestamp = datetime.datetime.now().strftime("%Y-%m-%d %H-%M-%S")
            if port is not None:
                try:
                    print("Connecting to device on {0} at baud: {1}".format(port, BAUD_RATE))
                    device = SerialHandler()
                    device.start(port, BAUD_RATE, timeout_seconds = 1, log_filename = "log/{0} SENSOR DATA".format(timestamp), log_extension = "csv", log_show_timestamp = True)
                except SerialException as e:
                    print("CONNECTION ERROR {0}".format(e))
                    port = None
                    valid = False
                    if device:
                        del device
                    device = None
            else:
                valid = False
            if valid:
                if device:
                    try:
                        device.send_string("1")
                    except SerialException as e:
                        print("Error initialising data collection {0}".format(e))
                print("Recording...")
                while (is_recording):
                    # Wait for S to be pressed
                    key = readkey.readkey(blocking = blocking_readkey)
                    time.sleep(0.1)
                    if key == 's':
                        is_recording = False
                        if device:
                            try:
                                device.send_string("0")
                                time.sleep(READ_DELAY_SECONDS)
                            except SerialException as e:
                                print("Error stopping data collection {0}".format(e))
                            del device
                print("Press R to start recording or Q to quit...")


if __name__ == '__main__':
    main()

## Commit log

2021-04-27 Changing code to be non-blocking, adding LED control via Serial
2021-04-27 Fixing prints for 3.5.3 compatibility
    [main.py]
2021-05-16 Patch for printing
2021-05-17 update sensors integration
